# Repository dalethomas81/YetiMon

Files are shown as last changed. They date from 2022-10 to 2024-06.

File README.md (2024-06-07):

# YetiMon
 
YetiMon is an open source add-on for your Goal Zero Yeti X series that monitors the voltage level of the battery and switches to an auxilary charging source such as AC mains once the capacity of the Yeti has depleted past a threshold.  

This is useful in applications where you want to use only solar power but want to automatically switch to another power such in situations where there has not been suficient sun to maintain your Yeti.  

Video describing how YetiMon works: https://youtu.be/-7pzLf8jMJA  
Video showing YetiMon installed: https://youtu.be/F3phBXkWJbo  
Video showing how to calibrate YetiMon: https://youtu.be/rwJIze3Ulzg  

More info to come!  

## Build Pictures
Money Shot  
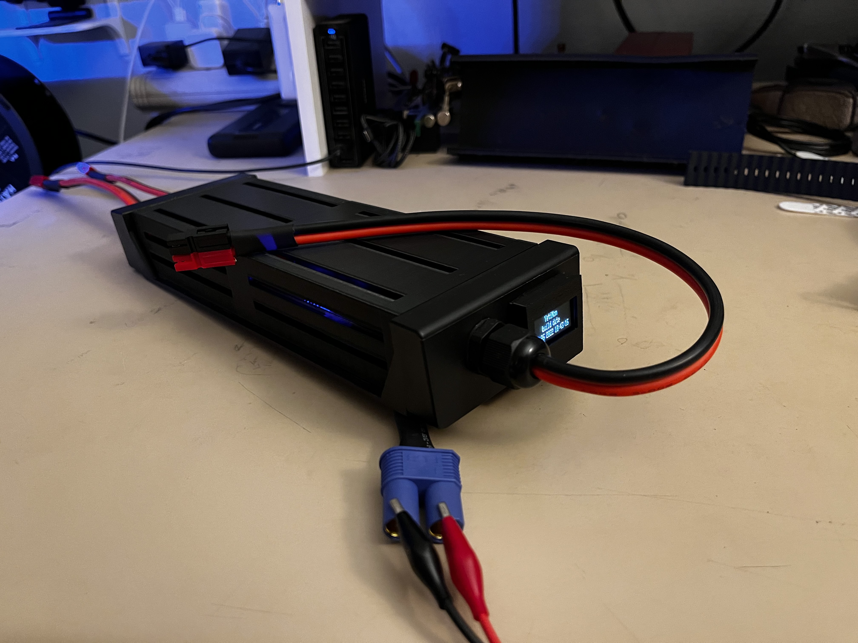
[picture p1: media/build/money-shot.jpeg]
  

Build  
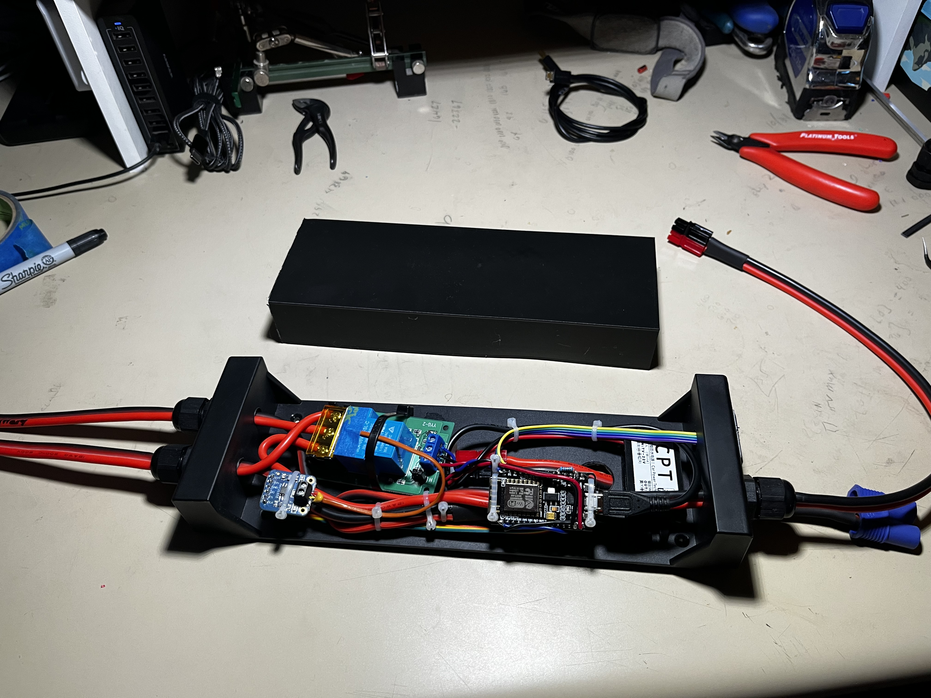
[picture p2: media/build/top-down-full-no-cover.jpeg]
  

Installed  
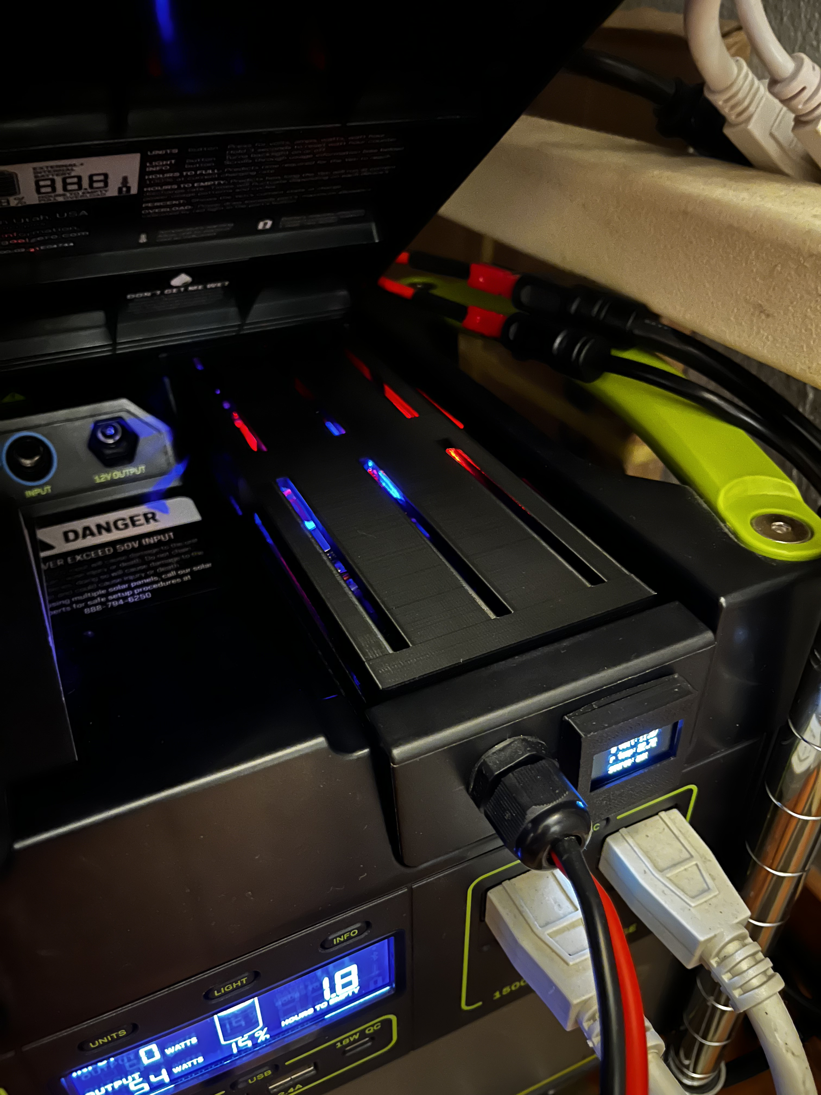
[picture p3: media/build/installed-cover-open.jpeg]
  

Display  
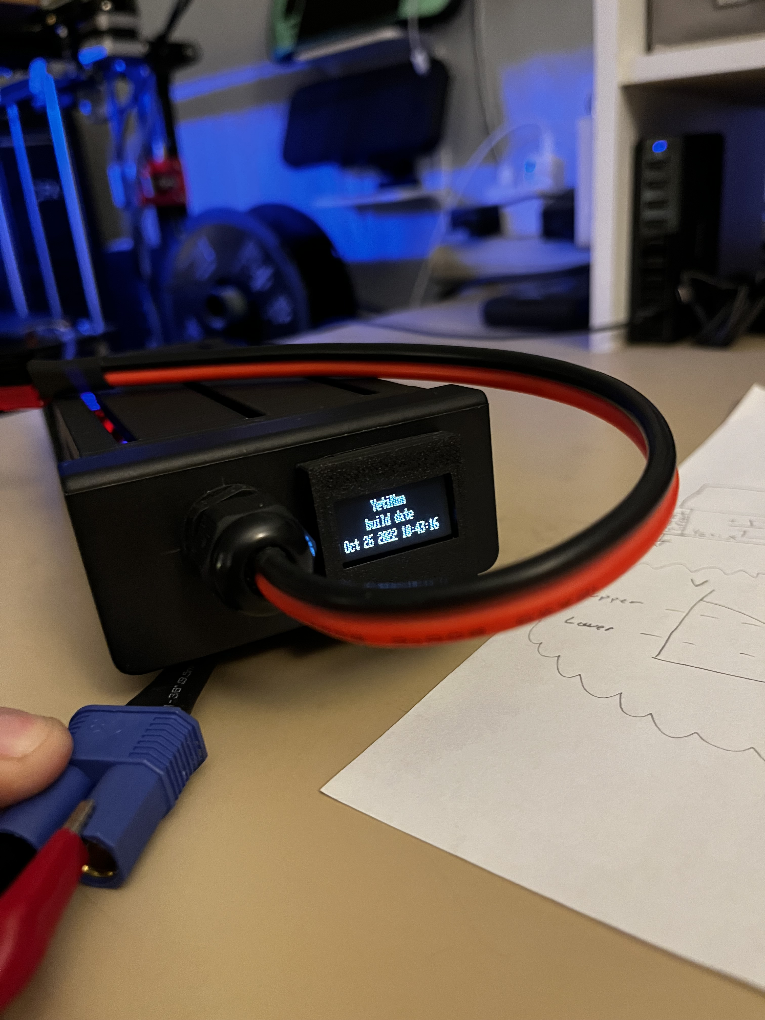
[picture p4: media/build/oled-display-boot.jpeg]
  

Functional Diagram  
menu  

Grafana  
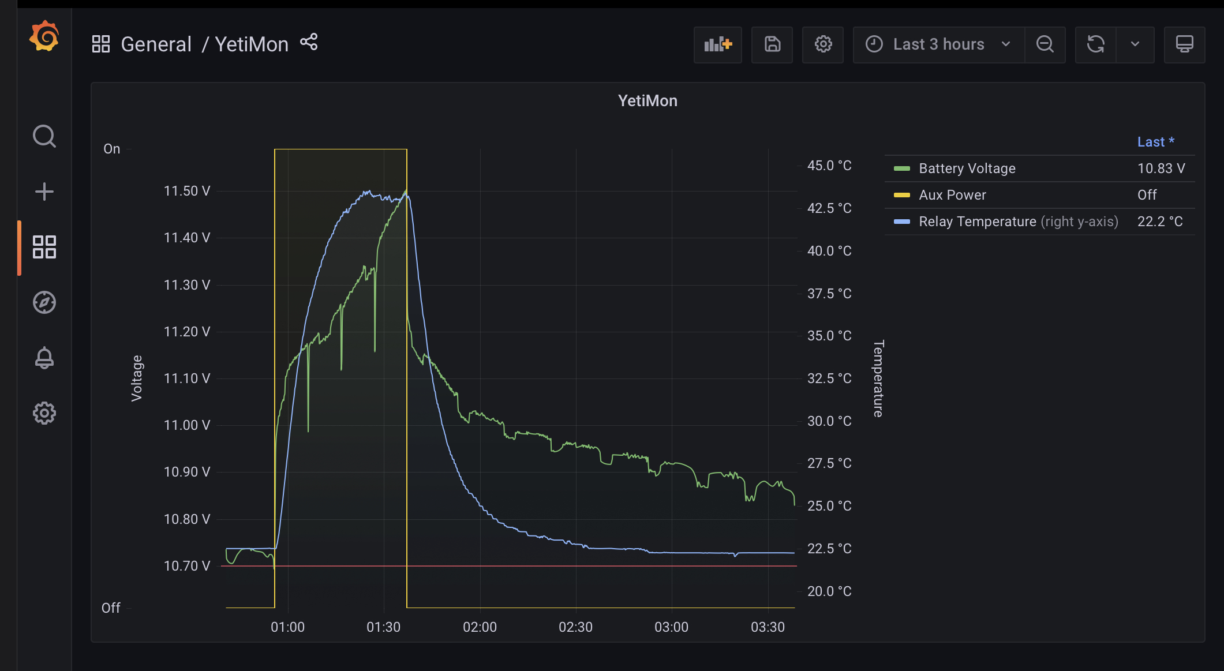
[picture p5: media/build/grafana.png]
  

Web app  
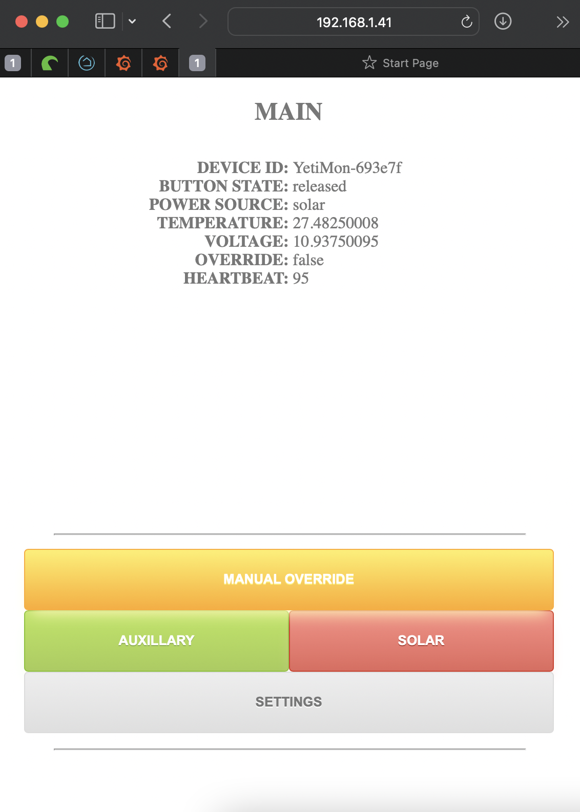
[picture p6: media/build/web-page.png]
  

## 3D Printing 

The "chassis" of YetiMon is just the factory cover that came with the Yeti X and is normally removed when you install a Yeti Link. What I did was use this as the chassis for YetiMon and 3D printed a cover that I made (link [here](source/cad/fusion-360)).  

The cover is quite large and had to be printed vertically on my Ender 5.
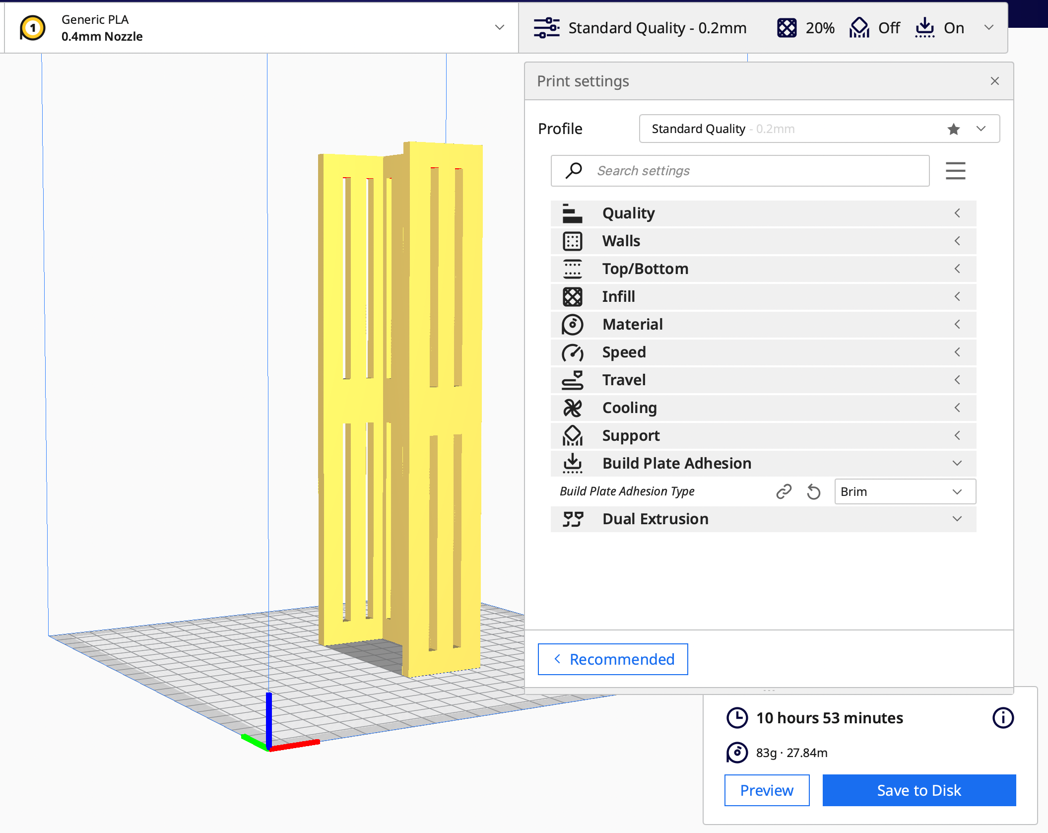
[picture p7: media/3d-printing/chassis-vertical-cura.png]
  

Additionally, I 3D printed a case for the oled display. I got this design off of Thingiverse. Hopefully the link still exist at the time of you reading this. If not, let me know and I will design one. [Here](https://www.thingiverse.com/thing:2176764) is the link.  

## Electrical Schematic  
Below is the Fritzing diagram that shows the connections clear as if they were made on a breadboard. The source file can be found [here](source/cad/fritzing).  

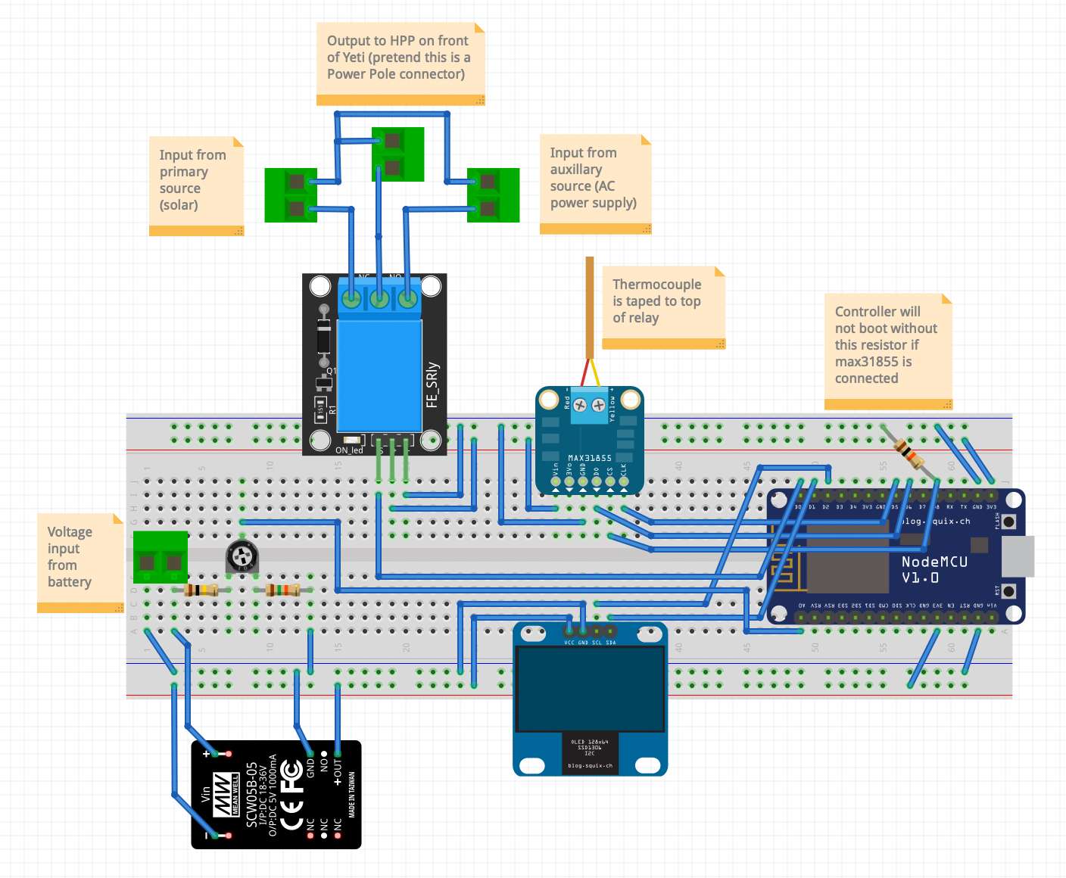
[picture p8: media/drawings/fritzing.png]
  

Sources for some of the Fritzing parts:  
https://github.com/squix78/esp8266-fritzing-parts  
https://github.com/adafruit/Fritzing-Library  
https://arduinomodules.info/ky-019-5v-relay-module/  

## Parts List  
Parts:  
| Part | Qty | Description | Link |
| ---- | --- | --- | ---- |
| MCU | 1 | NodeMCU ESP8266 Dev Board | |
| Relay | 1 | How power SPDT relay 30A | |
| Display | 1 | OLED Display SSD1306 128x64 | |
| Temp Sensor | 1 | MAX31855 thermocouple amplifier breakout | |
| Thermocouple | 1 | Type K thermoucouple | |
| Power Supply | 1 | 12v to 5v Buck converter with USB connector | |
| R1 | 1 | 100K resistor | |
| R2 | 1 | 10K potentiometer | |
| R3 | 1 | 15K resistor | |
| R4 | 1 | 10K resistor | |

Consumables:  
| Description | Link |
| --- | ---- |
| Power pole Connectors | |
| 12awg silicon wire | |
| Solid core wire | |
| Kapton tape | |
| Zip ties | |

Tools:  
1. Drill and bits
2. Soldering iron
3. Crimping tool
4. Wire strippers
5. Various small screwdrivers

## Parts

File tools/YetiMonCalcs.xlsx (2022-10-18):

Vin | 15 | Vin | 15
Vout | 2.70 | Vout | 2.40
Vout(max) | 3.32 | Vout(max) | 3.00
Vout(min) | 2.09 | Vout(min) | 1.80
R1 | 95000 | R1 | 100000
R2 | 10000 | R2 | 10000
R3 | 17000 | R3 | 15000
R4 | 100000 | R4 | 105000
R5 | 22000 | R5 | 20000

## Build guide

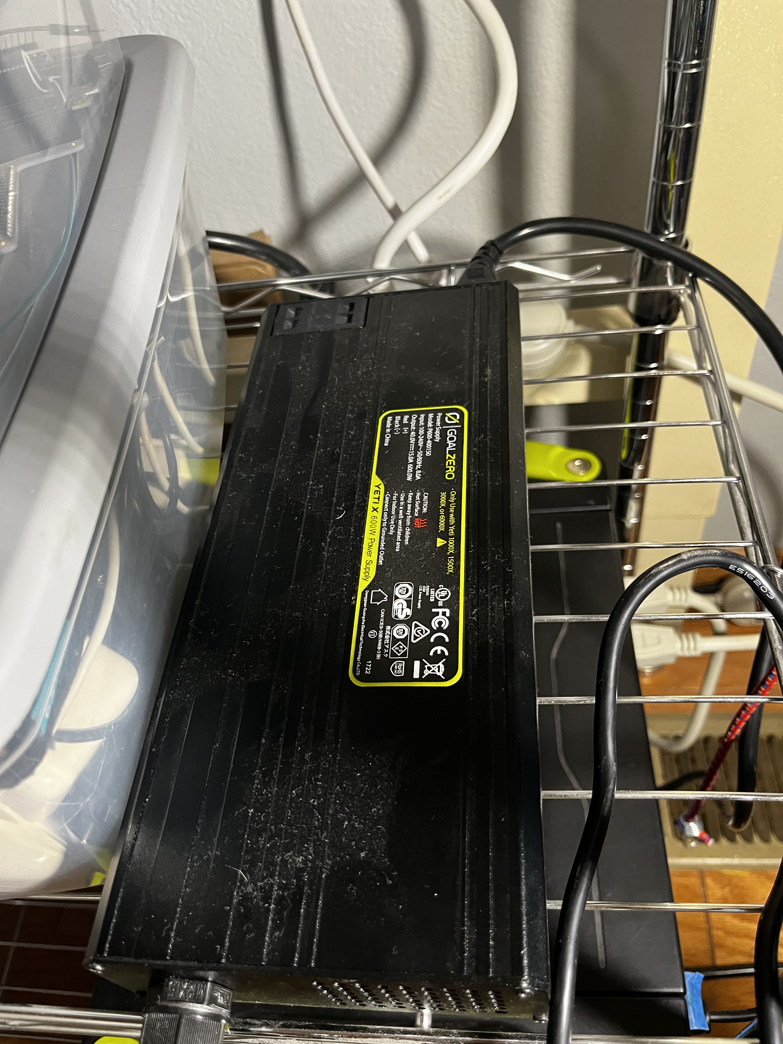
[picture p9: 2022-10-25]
media/build/wall-power-supply.jpeg

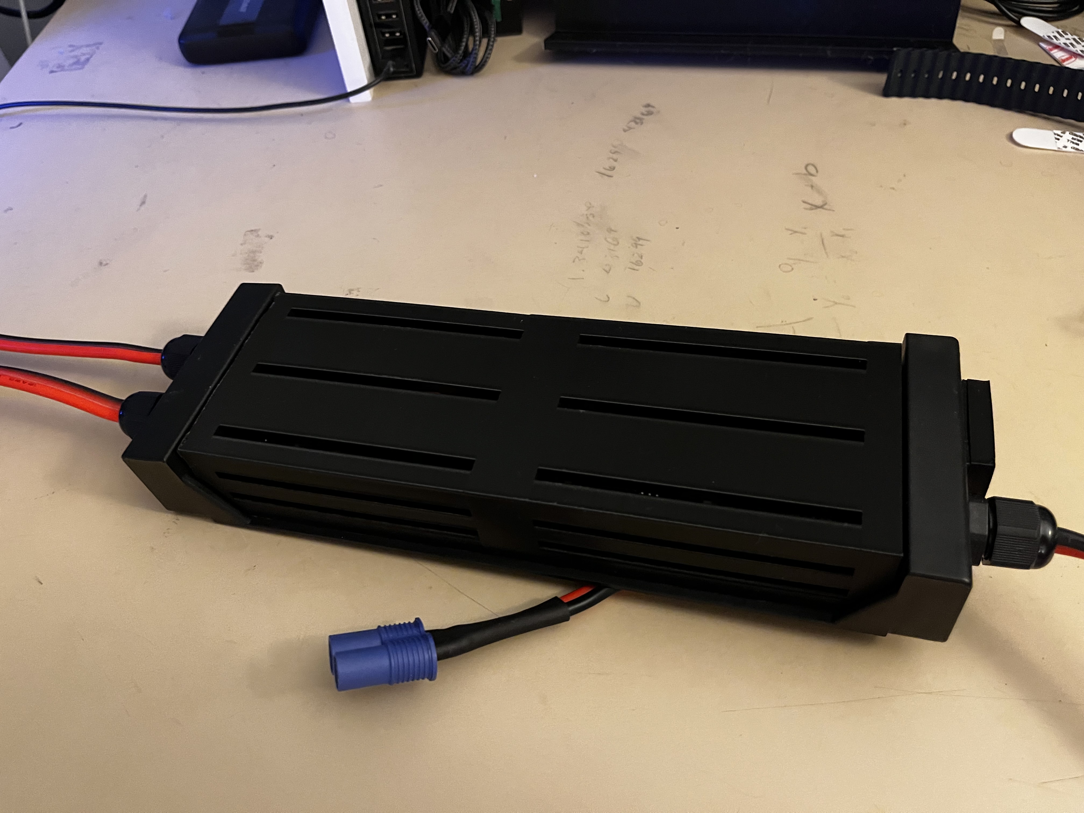
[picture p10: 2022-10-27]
media/build/cover-detail.jpeg

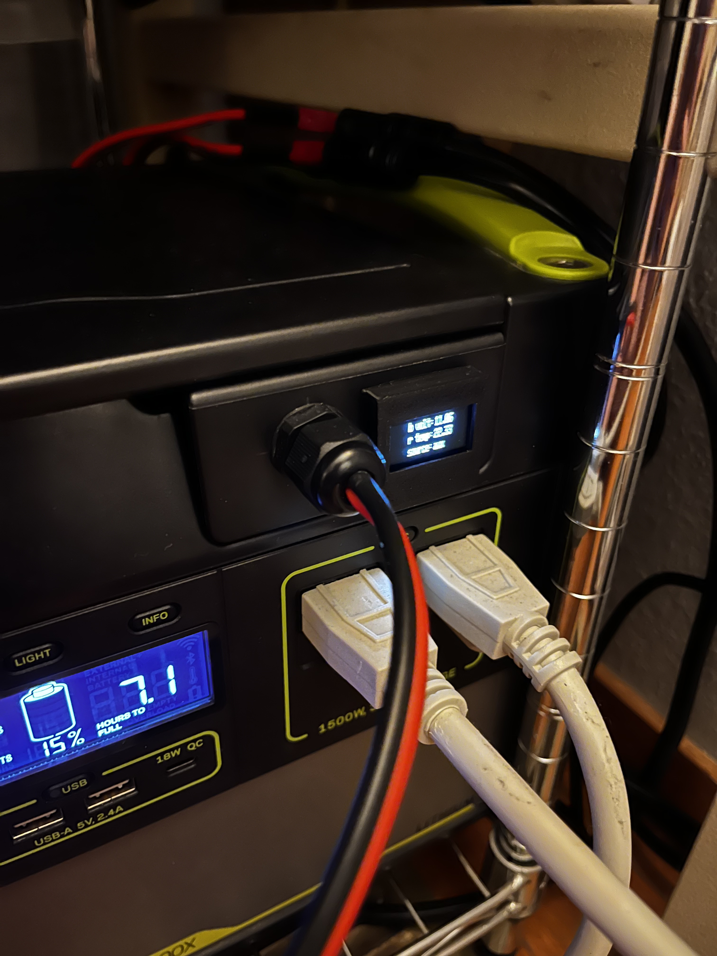
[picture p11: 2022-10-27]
media/build/installed-cover-closed.jpeg

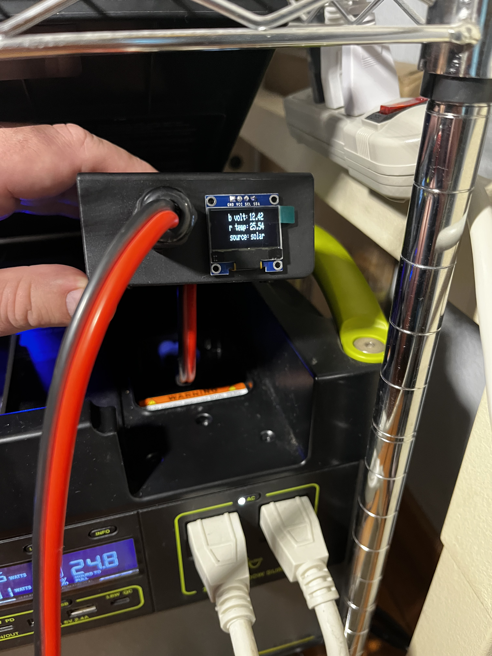
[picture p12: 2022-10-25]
media/build/installed-showing-cable.jpeg

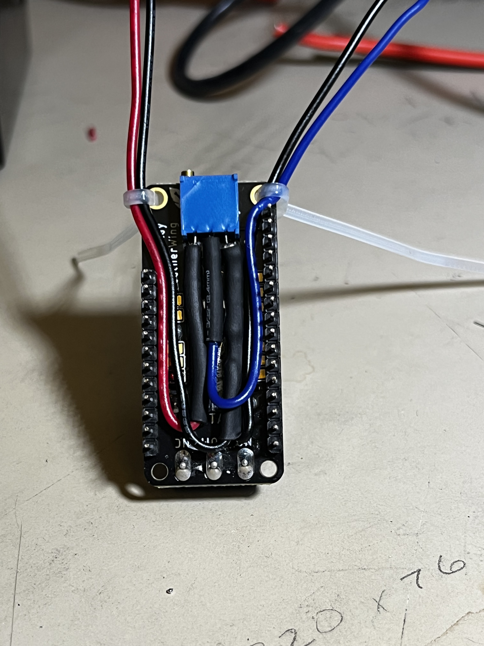
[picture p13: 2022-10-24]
media/build/pot-mount.jpeg

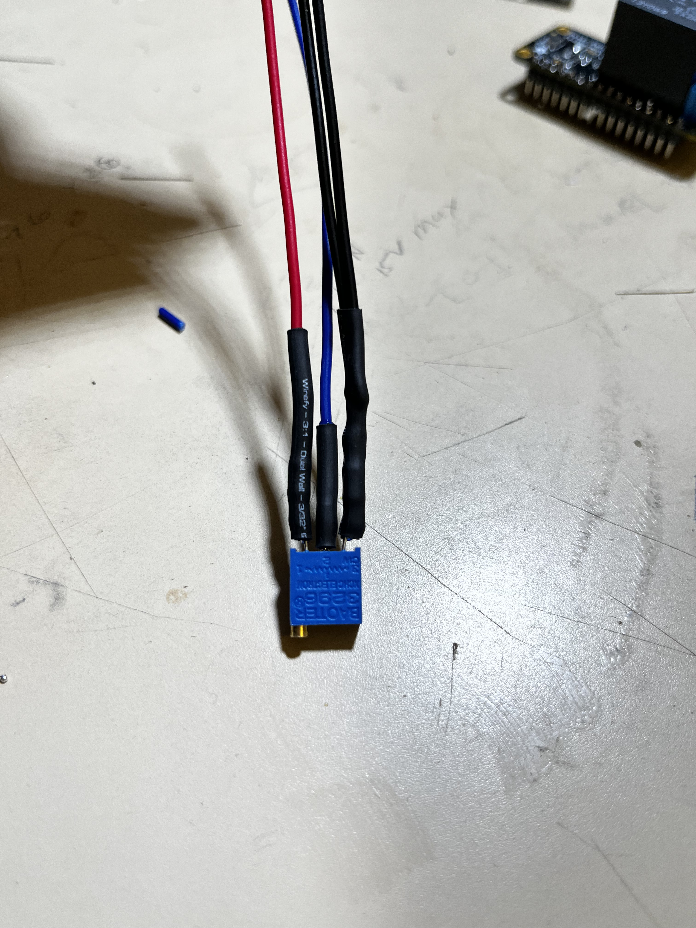
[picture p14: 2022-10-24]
media/build/potentiometer.jpeg

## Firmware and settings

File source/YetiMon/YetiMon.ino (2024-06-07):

/*

  https://github.com/dalethomas81/YetiMon
  Copyright (C) 2021  Dale Thomas

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
  DaleThomas@me.com

*/
/*************Board settings************

    Board Manager: http://arduino.esp8266.com/stable/package_esp8266com_index.json

    NodeMCU:
    "board": "esp8266:esp8266:nodemcuv2",
    "configuration": "xtal=160,vt=flash,exception=legacy,ssl=all,eesz=4M1M,led=2,ip=lm2f,dbg=Disabled,lvl=None____,wipe=none,baud=115200",

*****************************************/

#include <ArduinoJson.h>
#include "LittleFS.h"             // https://github.com/earlephilhower/arduino-littlefs-upload (this gets placed in the \.arduinoIDE\plugins folder)
#include <ESPAsyncWebServer.h>    // https://github.com/me-no-dev/ESPAsyncWebServer
#include <WebSocketsServer.h>     // https://github.com/Links2004/arduinoWebSockets
#include <ESPAsyncWiFiManager.h>  // https://github.com/alanswx/ESPAsyncWiFiManager
                                  // https://github.com/me-no-dev/ESPAsyncTCP
                                  // https://github.com/adafruit/Adafruit_SSD1306
#include <WebSocketsClient.h>
#include <ArduinoOTA.h>
#include <StreamString.h>
#include <SPI.h>
#include "Adafruit_MAX31855.h"

/* global defines */
#define CONST_DEVICE_ID           "YetiMon-"
#define WIFI_LISTENING_PORT       80
#define SERIAL_BAUD_RATE          115200

/* global variables */
const char version[] = __DATE__ " " __TIME__; 
String BUILD_DATE(version);
String DEVICE_ID(CONST_DEVICE_ID);

/* web server */
AsyncWebServer server(WIFI_LISTENING_PORT);
WebSocketsServer webSocket_Server = WebSocketsServer(WIFI_LISTENING_PORT+1);
WebSocketsClient webSocket_Client;

/* wifi */
DNSServer dns;
char ws_server_ip[16] = "192.168.1.1";
char ws_server_port[6] = "81";
char ws_server_url[10] = "/";
bool shouldSaveConfig = false;
void checkWifi() {
  if ((WiFi.status() != WL_CONNECTED) || (WiFi.localIP().toString() == "0.0.0.0")) { 
    //Serial.println("Reconnecting to Wifi");
    WiFi.reconnect();
    //connectWifi(0);
  }
}
void saveConfigCallback () {
  //Serial.println("Should save config");
  shouldSaveConfig = true;
}
void setupWifiManager() {   
  // The extra parameters to be configured (can be either global or just in the setup)
  // After connecting, parameter.getValue() will get you the configured value
  // id/name placeholder/prompt default length
  AsyncWiFiManagerParameter custom_ws_server_ip("server", "ws server ip", ws_server_ip, 16);
  AsyncWiFiManagerParameter custom_ws_server_port("port", "ws server port", ws_server_port, 6);
  AsyncWiFiManagerParameter custom_ws_server_url("url", "ws server url", ws_server_url, 10);
  // Local intialization. Once its business is done, there is no need to keep it around
  AsyncWiFiManager wifiManager(&server,&dns);
  //set config save notify callback
  wifiManager.setSaveConfigCallback(saveConfigCallback);
  //add all your parameters here
  wifiManager.addParameter(&custom_ws_server_ip);
  wifiManager.addParameter(&custom_ws_server_port);
  wifiManager.addParameter(&custom_ws_server_url);

  //reset settings - for testing
  //wifiManager.resetSettings();

  //set minimum quality of signal so it ignores AP's under that quality
  //defaults to 8%
  wifiManager.setMinimumSignalQuality();
  
  // set custom ip for portal
  //wifiManager.setAPConfig(IPAddress(10,0,1,1), IPAddress(10,0,1,1), IPAddress(255,255,255,0));

  wifiManager.autoConnect(DEVICE_ID.c_str());

  //read updated parameters
  strcpy(ws_server_ip, custom_ws_server_ip.getValue());
  strcpy(ws_server_port, custom_ws_server_port.getValue());
  strcpy(ws_server_url, custom_ws_server_url.getValue()); 
  
  //save the custom parameters to FS
  if (shouldSaveConfig) {
    saveConfig();
  }
  //WiFi.mode(WIFI_STA);
  //WiFi.begin();
  //WiFi.setAutoReconnect(true);
  //WiFi.persistent(true);
}
void handleEraseConfig() {
    Serial.println("Erasing configuration and restarting.");
    ESP.eraseConfig();
    ESP.reset();
}

/* utility */
#define HEARTBEAT_TIME  1000
uint8_t HEARTBEAT_VALUE;
bool HeartbeatOn = false;
unsigned long timer_heartbeat;
unsigned long timer_eraseConfig;
void handleHeartbeat(){
  if (millis() - timer_heartbeat > HEARTBEAT_TIME ){
    timer_heartbeat = millis();
    //broadcastUpdates(); // send out websockets updates
    if (HEARTBEAT_VALUE>=100) {
      HEARTBEAT_VALUE = 0;
    } else {
      HEARTBEAT_VALUE = HEARTBEAT_VALUE + 1;
    }
    if (HeartbeatOn) {
      HeartbeatOn = false;
      //Serial.println("Heartbeat Off");
    } else {
      HeartbeatOn = true;
      //Serial.println("Heartbeat On");
    }
  }
}

/* flash */
void initLittleFS() {

  Serial.println(F("Inizializing FS..."));
  if (LittleFS.begin()){
      Serial.println(F("done."));
  }else{
      Serial.println(F("fail."));
  }

  // // To format all space in LittleFS
  //  //LittleFS.format();

  // // Get all information of your LittleFS
  // FSInfo fs_info;
  // LittleFS.info(fs_info);

  // Serial.println("File system info.");

  // Serial.print("Total space:      ");
  // Serial.print(fs_info.totalBytes);
  // Serial.println("byte");

  // Serial.print("Total space used: ");
  // Serial.print(fs_info.usedBytes);
  // Serial.println("byte");

  // Serial.print("Block size:       ");
  // Serial.print(fs_info.blockSize);
  // Serial.println("byte");

  // Serial.print("Page size:        ");
  // Serial.print(fs_info.totalBytes);
  // Serial.println("byte");

  // Serial.print("Max open files:   ");
  // Serial.println(fs_info.maxOpenFiles);

  // Serial.print("Max path length:  ");
  // Serial.println(fs_info.maxPathLength);

  // Serial.println();

  // // Open dir folder
  // Dir dir = LittleFS.openDir("/");
  // // Cycle all the content
  // while (dir.next()) {
  //     // get filename
  //     Serial.print(dir.fileName());
  //     Serial.print(" - ");
  //     // If element have a size display It else write 0
  //     if(dir.fileSize()) {
  //         File f = dir.openFile("r");
  //         Serial.println(f.size());
  //         f.close();
  //     }else{
  //         Serial.println("0");
  //     }
  // }
}

/* webserver */
void setupWebserver() {
  server.on("/", HTTP_GET, [](AsyncWebServerRequest *request){ // https://github.com/me-no-dev/ESPAsyncWebServer
    request->send(LittleFS, "/MAIN.html");
  });
  server.on("/main", HTTP_GET, [](AsyncWebServerRequest *request){
    request->send(LittleFS, "/MAIN.html");
  });
  server.on("/settings", HTTP_GET, [](AsyncWebServerRequest *request){
    request->send(LittleFS, "/SETTINGS.html");
  });
  server.on("/favicon.ico", HTTP_GET, [](AsyncWebServerRequest *request){
    request->send(LittleFS, "/favicon.ico");
  });
  server.on("/apple-touch-icon.png", HTTP_GET, [](AsyncWebServerRequest *request){
    request->send(LittleFS, "/apple-touch-icon.png");
  });
  server.on("/favicon-16x16.png", HTTP_GET, [](AsyncWebServerRequest *request){
    request->send(LittleFS, "/favicon-16x16.png");
  });
  server.on("/apple-touch-icon.png", HTTP_GET, [](AsyncWebServerRequest *request){
    request->send(LittleFS, "/apple-touch-icon.png");
  });
  server.on("/favicon-32x32.png", HTTP_GET, [](AsyncWebServerRequest *request){
    request->send(LittleFS, "/favicon-32x32.png");
  });
  server.on("/favicon-16x16.png", HTTP_GET, [](AsyncWebServerRequest *request){
    request->send(LittleFS, "/favicon-16x16.png");
  });
  server.on("/site.webmanifest", HTTP_GET, [](AsyncWebServerRequest *request){
    request->send(LittleFS, "/site.webmanifest");
  });
  server.begin();
}

/* i/o */
#define ERASE_CONFIG_TIME             10000   // how long to hold down the button to erase config in ms
#define GPIO_LED                      D4      // D4 is LED on nodemcu
#define GPIO_BUTTON                   D3      // D3 is flash button on nodemcu
#define GPIO_RELAY                    D0      // D0 is HIGH at boot
#define GPIO_VOLTAGE_INPUT            A0      // A0 is the only analog input on esp8266
#define AVG_VOLTAGE_SIZE              100     // size of the array for smoothing analog in
#define AVG_TEMPERATURE_SIZE          100     // size of the array for smoothing analog in
#define SAMPLE_INTERVAL               100     // how often to sample the voltage in ms
#define BROADCAST_RATE_LIMIT          2000    // limit the rate we can print/broadcast updates in ms
#define BROADCAST_VOLT_TOLERANCE      0.01    // voltage tolerance to print/broadcast
#define BROADCAST_TEMP_TOLERANCE      0.01    // temp tolerance to print/broadcast
#define DEBOUNCE_DELAY                50      // the debounce time for hardware buttons
#define MAXDO                         D6
#define MAXCS                         D8      // !!!!! WARNING !!!! pull this bad boy low with a ~10K resistor or the ESP will not boot.
#define MAXCLK                        D5
Adafruit_MAX31855 thermocouple(MAXCLK, MAXCS, MAXDO);
float temperatureSensorValue = 0.0;
float temperatureReadings[AVG_TEMPERATURE_SIZE] = {0.0};
int temperatureArrayIndex = 0;
float previousBroadcastedTemperature, totalTemperature, averageTemperature;
int buttonState = true; 
int previousButtonState = buttonState;
bool relayState = false;  // our relay is off when false
bool previousRelayState = relayState;
unsigned long lastDebounceTime = 0;
double voltageUpperLimit = 11.80; // switches to solar when battery rises to this voltage
double voltageLowerLimit = 10.80; // switches to auxillary when battery drops to this voltage
long long voltageLimitDelay = 10000; // how long to be under/over the limits before switching to aux in ms
int voltageSensorValue = 0;
float voltageReadings[AVG_VOLTAGE_SIZE] = {0.0};
int voltageArrayIndex = 0;
float previousBroadcastedVoltage, voltageValue, totalVoltage, averageVoltage;
unsigned long previousLimitMillis, previousSampleMillis, previousPrintMillis;
bool manualOverride = false;
void setupIO() {
  pinMode(GPIO_LED, OUTPUT);
  digitalWrite(GPIO_LED, !relayState); // nodemcu led is off when low
  
  pinMode(GPIO_RELAY, OUTPUT);
  digitalWrite(GPIO_RELAY, relayState); // our relay is off when high
  
  pinMode(GPIO_BUTTON, INPUT_PULLUP);
  
  thermocouple.begin();
}
void handleIO() {
  // read the state of the switch into a local variable:
  int reading = digitalRead(GPIO_BUTTON);

  // if button is held down for the alloted time the config portal will start
  if (reading > 0) { // keep resetting timer until pressed
    timer_eraseConfig = millis();
  }
  if (millis() - timer_eraseConfig > ERASE_CONFIG_TIME) {
    handleEraseConfig();
  }

  // check to see if you just pressed the button
  // (i.e. the input went from LOW to HIGH), and you've waited long enough
  // since the last press to ignore any noise:

  // If the switch changed, due to noise or pressing:
  if (reading != previousButtonState) {
    // reset the debouncing timer
    lastDebounceTime = millis();
  }

  if ((millis() - lastDebounceTime) > DEBOUNCE_DELAY) {
    // whatever the reading is at, it's been there for longer than the debounce
    // delay, so take it as the actual current state:

    // if the button state has changed:
    if (reading != buttonState) {
      buttonState = reading;

      // only toggle the LED if the new button state is HIGH
      if (buttonState == true) {
        relayState = !relayState;
        previousLimitMillis = millis();
      }

      broadcastUpdates(); // send out websockets updates

    }
  }
  
  unsigned long currentMillis = millis();
  if (currentMillis - previousSampleMillis >= SAMPLE_INTERVAL) {
    previousSampleMillis = currentMillis;

    // TODO scaling should either be configurable or dynamic. can we detect the board type dynamically??
    // get voltage
    voltageSensorValue = analogRead(GPIO_VOLTAGE_INPUT);
    // voltageSensorValue * scaled-input-to-controller * scaled-input-to-voltage-divider(this term from spreadsheet)
    //voltageValue = voltageSensorValue * (5.0 / 1023.0) * (15.0 / 5.0); // aruduino uno at328
    //voltageValue = voltageSensorValue * (3.3 / 4095.0) * (15.0 / 2.4); // adafruit feather esp32
    voltageValue = voltageSensorValue * (3.3 / 1023.0) * (15.0 / 2.4); // nodemcu esp8266

    // smoothing - voltage
    voltageReadings[voltageArrayIndex] = voltageValue;
    if (voltageArrayIndex >= AVG_VOLTAGE_SIZE - 1){
      voltageArrayIndex = 0;
    } else {
      voltageArrayIndex++;
    }
    totalVoltage = 0.0;
    // TODO this average should grow with the number of samples if we want to have a correct average for the first n = AVG_VOLATAGE_SIZE samples
    for (int i = 0; i <= AVG_VOLTAGE_SIZE - 1; i++){
      totalVoltage = totalVoltage + voltageReadings[i];
    }
    averageVoltage = totalVoltage / AVG_VOLTAGE_SIZE;

    // get temperature
    double temperatureSensorValue = thermocouple.readCelsius();
    //Serial.println(thermocouple.readFahrenheit());
    //Serial.println(thermocouple.readInternal());
    
    // smoothing - temperature
    temperatureReadings[temperatureArrayIndex] = temperatureSensorValue;
    if (temperatureArrayIndex >= AVG_TEMPERATURE_SIZE - 1){
      temperatureArrayIndex = 0;
    } else {
      temperatureArrayIndex++;
    }
    totalTemperature = 0.0;
    // TODO this average should grow with the number of samples if we want to have a correct average for the first n = AVG_TEMPERATURE_SIZE samples
    for (int i = 0; i <= AVG_TEMPERATURE_SIZE - 1; i++){
      totalTemperature = totalTemperature + temperatureReadings[i];
    }
    averageTemperature = totalTemperature / AVG_TEMPERATURE_SIZE;
    
  }

  // write to i/o
  digitalWrite(GPIO_LED, !relayState);
  digitalWrite(GPIO_RELAY, relayState);

  previousButtonState = reading;
}
void monitorIO() {
  unsigned long currentMillis = millis();

  // process results vs limits
  if ((double)averageVoltage < voltageLowerLimit && !manualOverride){
    if (currentMillis - previousLimitMillis >= voltageLimitDelay) {
      relayState = true;
    }
  } else if ((double)averageVoltage > voltageUpperLimit && !manualOverride) {
    if (currentMillis - previousLimitMillis >= voltageLimitDelay) {
      relayState = false;
    }
  } else {
    previousLimitMillis = currentMillis;
  }

  // if voltage/temperature value changes enough send out an update to clients
  if (((averageVoltage > previousBroadcastedVoltage + BROADCAST_VOLT_TOLERANCE ||
      averageVoltage < previousBroadcastedVoltage - BROADCAST_VOLT_TOLERANCE || 
      averageTemperature > previousBroadcastedTemperature + BROADCAST_TEMP_TOLERANCE ||
      averageTemperature < previousBroadcastedTemperature - BROADCAST_TEMP_TOLERANCE) &&
      currentMillis - previousPrintMillis >= BROADCAST_RATE_LIMIT) ||
      relayState != previousRelayState){
        
      previousPrintMillis = currentMillis;
      previousBroadcastedVoltage = averageVoltage;
      previousBroadcastedTemperature = averageTemperature;
      previousRelayState = relayState;
      broadcastUpdates();
      updateDisplay();

      Serial.print("sensor=");
      Serial.print(voltageSensorValue); 
      Serial.print(" | avg voltage=");
      Serial.print(averageVoltage); 
      Serial.print(" | avg temperature=");
      Serial.print(averageTemperature); 
      Serial.print(" | output1=");
      Serial.print(relayState);
      Serial.println();
    
  }
}

/* display */
#include <Wire.h>
#include <Adafruit_GFX.h>
#include <Adafruit_SSD1306.h>
#define SCREEN_WIDTH 128 // OLED display width, in pixels
#define SCREEN_HEIGHT 32 // OLED display height, in pixels
// Declaration for an SSD1306 display connected to I2C (SDA, SCL pins)
#define OLED_RESET     -1 // Reset pin # (or -1 if sharing Arduino reset pin)
Adafruit_SSD1306 display(SCREEN_WIDTH, SCREEN_HEIGHT, &Wire, OLED_RESET);
bool refreshDisplay;
void setupDisplay(){
  display.begin(SSD1306_SWITCHCAPVCC, 0x3C);
  display.clearDisplay();
  display.setTextSize(1);      // Normal 1:1 pixel scale
  display.setTextColor(SSD1306_WHITE); // Draw white text
  display.setCursor(40,0); display.print("YetiMon");
  display.setCursor(30,10); display.print("build date");
  display.setCursor(0,20); display.print(BUILD_DATE);
  display.display();
  //delay(1000);
}
void handleDisplay(){
  if (refreshDisplay){
    refreshDisplay = false;
    //display.setCursor(0, 0);
    //display.write(' ')
    //display.display();
  }
}
void updateDisplay(){
  int i1stColumn = 30; int i2ndColumn = 75;
  int i1stRow = 0; int i2ndRow = 10; int i3rdRow = 20;
  display.clearDisplay();
  display.setCursor(i1stColumn, i1stRow); display.print("b volt: "); // (x,y)
  display.setCursor(i2ndColumn, i1stRow); display.print(averageVoltage);
  display.setCursor(i1stColumn, i2ndRow); display.print("r temp: ");
  display.setCursor(i2ndColumn, i2ndRow); display.print(averageTemperature);
  display.setCursor(i1stColumn, i3rdRow); display.print("source: ");
  display.setCursor(i2ndColumn, i3rdRow); if (relayState) display.print("aux"); else display.print("solar");
  display.display();
}

/* ota */
//#define OTA_PASSWORD    "ESPsAreGreat!"
bool OtaInProgress = false;
int progress_last = 0;
void setupOTA(){
  // Port defaults to 8266
  // ArduinoOTA.setPort(8266);
  // Hostname defaults to esp8266-[ChipID]
  ArduinoOTA.setHostname(DEVICE_ID.c_str());
  // No authentication by default
  //ArduinoOTA.setPassword((const char *)OTA_PASSWORD); // using password isnt supported in vscode...yet
  ArduinoOTA.onStart([]() {
    OtaInProgress = true;
    webSocket_Server.onEvent(NULL);
    webSocket_Client.onEvent(NULL);
    LittleFS.end();
    Serial.println("Start");
  });
  ArduinoOTA.onEnd([]() {
    OtaInProgress = false;
    Serial.println("\nEnd");
    display.clearDisplay();
    // (column, row)
    display.setCursor(15, 0); display.print("update complete");
    display.setCursor(10, 10); display.print("so long and thanks");
    display.setCursor(10, 20); display.print("for all the fish!");
    display.display();
    ESP.restart();
  });
  ArduinoOTA.onProgress([](unsigned int progress, unsigned int total) {
    if (progress != progress_last) {
      progress_last = progress;
      Serial.printf("Progress: %u%%\r\n", (progress / (total / 100)));
      display.clearDisplay();
      // (column, row)
      display.setCursor(10, 0); display.print("updating firmware");
      display.setCursor(5, 10); display.print("do not remove power!");
      display.setCursor(20, 20); display.printf("Progress: %u%%\r\n", (progress / (total / 100)));
      display.display();
    }
  });
  ArduinoOTA.onError([](ota_error_t error) {
    OtaInProgress = false;
    Serial.printf("Error[%u]: ", error);
    if (error == OTA_AUTH_ERROR) Serial.println("Auth Failed");
    else if (error == OTA_BEGIN_ERROR) Serial.println("Begin Failed");
    else if (error == OTA_CONNECT_ERROR) Serial.println("Connect Failed. Firewall issue?");
    else if (error == OTA_RECEIVE_ERROR) Serial.println("Receive Failed");
    else if (error == OTA_END_ERROR) Serial.println("End Failed");
  });
  ArduinoOTA.begin();
}

/* websockets */
#define PAYLOAD_SIZE_IN 200
#define PAYLOAD_SIZE_OUT 200
enum SettingsUpdateType{
  SaveSuccess, SaveFailure, SettingsBroadcast
};
void parseWebSocketMessage(JsonDocument& jsonBuffer); // need prototype because complex argument and arduino gets confused
void setupWebsocket() {
  webSocket_Server.begin();
  webSocket_Server.onEvent(webSocketEvent_Server);
  
  webSocket_Client.begin(ws_server_ip, atoi(ws_server_port), ws_server_url); // server address, port and URL
  webSocket_Client.onEvent(webSocketEvent_Client);
  //webSocket_Client.setAuthorization("user", "Password");
  webSocket_Client.setReconnectInterval(5000);
  // start heartbeat (optional)
  // ping server every 15000 ms
  // expect pong from server within 3000 ms
  // consider connection disconnected if pong is not received 2 times
  //webSocket_Client.enableHeartbeat(15000, 3000, 2);
}
void broadcastUpdates() {
  /*
  {
  "topic":"status",
    "data": {
      "DEVICE_ID": "ESP-xxxxxx",
      "HEARTBEAT_VALUE": 100,
      "BUTTON_STATE": true,
      "RELAY_STATE": true
    }
  }
  */
  DynamicJsonDocument  jsonBuffer(PAYLOAD_SIZE_OUT); // https://arduinojson.org/v6/assistant/

  StreamString payload;
  
  jsonBuffer["topic"] = "status";
  jsonBuffer["data"]["device_id"] = DEVICE_ID.c_str();
  jsonBuffer["data"]["device_addr"] = WiFi.localIP().toString(); // causing boot loop
  jsonBuffer["data"]["device_build"] = BUILD_DATE.c_str();
  jsonBuffer["data"]["heartbeat_value"] = HEARTBEAT_VALUE; 

  jsonBuffer["data"]["button_state"] = (bool)buttonState;
  jsonBuffer["data"]["relay_state"] = (bool)relayState; // our relay is off when high
  jsonBuffer["data"]["avg_voltage"] = (float)averageVoltage;
  jsonBuffer["data"]["avg_temperature"] = (float)averageTemperature;
  jsonBuffer["data"]["manual_override"] = (bool)manualOverride;

  serializeJson(jsonBuffer,payload);

  webSocket_Server.broadcastTXT(payload);
  webSocket_Client.sendTXT(payload);
}
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
void loop() {
  //
  // handle logic
  //
  if (!OtaInProgress) {
    //checkWifi();
    handleIO();
    monitorIO();
    handleDisplay();
    handleHeartbeat();
    webSocket_Server.loop();
    webSocket_Client.loop();
  }
  ArduinoOTA.handle();
  
  //
  // take a breather
  //
  yield();
}

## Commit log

2022-10-21 refactoring. add voltage to web.
2022-10-21 add button. comment. limit time
2022-10-26 calibration video. change limits.
2022-10-27 refactor repo. electrical schematic.
    [main.sch, schematic.fzz]
2022-11-06 add toggle
    [schematic.fzz]
2024-06-05 add voltage settings to configuration
    - added key value pairs to the configuration file for voltage monitoring settings.
2024-06-06 add save function
    - added button to send a settings save command to yetimon.
    - added logic to save the configuration on a save command.
    - added a response for success/failure after saving.
    - added a settings broadcast that will send the current settings to the client.
    [YetiMon.ino]
2024-06-06 clean up main web page
    - set the decimal places of the voltage and temperature readings to 2

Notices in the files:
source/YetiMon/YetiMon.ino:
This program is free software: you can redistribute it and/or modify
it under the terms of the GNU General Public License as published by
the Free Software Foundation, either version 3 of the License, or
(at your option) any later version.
